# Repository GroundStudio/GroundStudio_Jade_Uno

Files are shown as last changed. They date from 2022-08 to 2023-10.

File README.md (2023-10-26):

GroundStudio Jade Uno
====================================
(https://ardushop.ro/ro/home/1728-placa-de-dezvoltare-jade-uno.html)

Get it from [ardushop.ro](https://ardushop.ro/ro/home/1728-placa-de-dezvoltare-jade-uno.html)

Explore all the GroundStudio products at [GroundStudio.ro](https://groundstudio.ro/)

Description
-------------------
ATMEGA328P based development board, 32kBytes of In-System Self-Programmable Flash program memory,  1kBytes EEPROM, 2kBytes Internal SRAM, 6 PWM Channels, 20 Digital Pins including 4 channel 10 bit ADC Pins and HT42B534-2 for USB comunication.

Contents
-------------------

* [/Documentation](https://github.com/GroundStudio/GroundStudio_Jade_Uno/tree/main/Documentation) -- Pinout.
* [/Hardware](https://github.com/GroundStudio/GroundStudio_Jade_Uno/tree/main/Hardware) -- Schematics, layout.

Versions
-------------------
*(Not all tags shown)*

* [REV0.2]

License
-------------------

This is released under the [Attribution-ShareAlike 4.0 International (CC BY-SA 4.0)](https://creativecommons.org/licenses/by-sa/4.0/) license.
**You are welcome to use this for commercial purposes.**

Please consider contributing back to this project or others to help the open-source hardware community continue to thrive and grow!

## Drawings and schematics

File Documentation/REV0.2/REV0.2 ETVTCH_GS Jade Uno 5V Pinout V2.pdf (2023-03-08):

# GroundStudio Jade Uno

## ISP Port

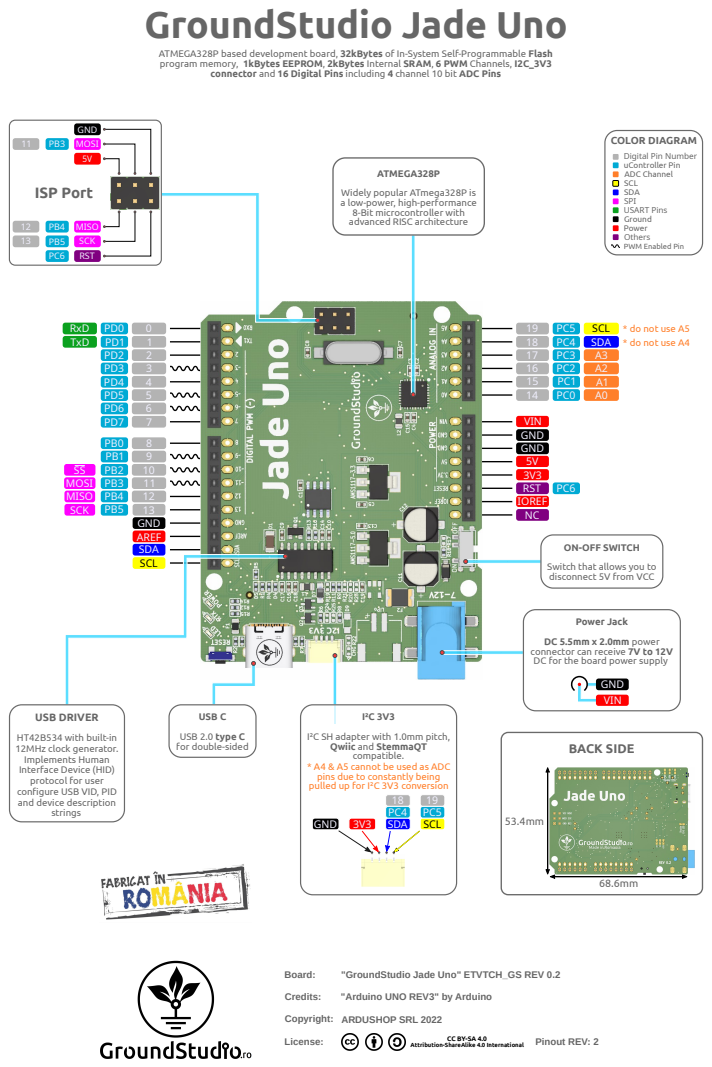
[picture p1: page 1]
Board:; Credits:; "Arduino UNO REV3" by Arduino; Copyright:; License:; ARDUSHOP SRL 2022; Pinout REV: 2; ATMEGA328P; GND MOSI 5V; PB5 SCK; MISO; RST; MOSI PB3; MISO PB4; TxD PD1; RxD PD0; SCK PB5; SCL; SDA; AREF; GND; VIN; RST PC6; IOREF; USB DRIVER; strings; BACK SIDE; I²C 3V3; SDA SCL; GND 3V3; * do not use A5 * do not use A4

ATMEGA328P based development board, 32kBytes of In-System Self-Programmable Flash
program memory, 1kBytes EEPROM, 2kBytes Internal SRAM, 6 PWM Channels, I2C_3V3

connector and 16 Digital Pins including 4 channel 10 bit ADC Pins

COLOR DIAGRAM
Digital Pin Number
uController Pin
ADC Channel
SCL
SDA
SPI
USART Pins
Ground
Power
Others
PWM Enabled Pin

Widely popular ATmega328P is
a low-power, high-performance
8-Bit microcontroller with
advanced RISC architecture

ON-OFF SWITCH
Switch that allows you to
disconnect 5V from VCC

Power Jack
DC 5.5mm x 2.0mm power
connector can receive 7V to 12V
DC for the board power supply

USB C
USB 2.0 type C
for double-sided

HT42B534 with built-in
12MHz clock generator.
Implements Human
Interface Device (HID)
protocol for user
configure USB VID, PID
and device description

I²C SH adapter with 1.0mm pitch,
Qwiic and StemmaQT
compatible.

* A4 & A5 cannot be used as ADC
pins due to constantly being
pulled up for I²C 3V3 conversion

"GroundStudio Jade Uno" ETVTCH_GS REV 0.2

Attribution-ShareAlike 4.0 International

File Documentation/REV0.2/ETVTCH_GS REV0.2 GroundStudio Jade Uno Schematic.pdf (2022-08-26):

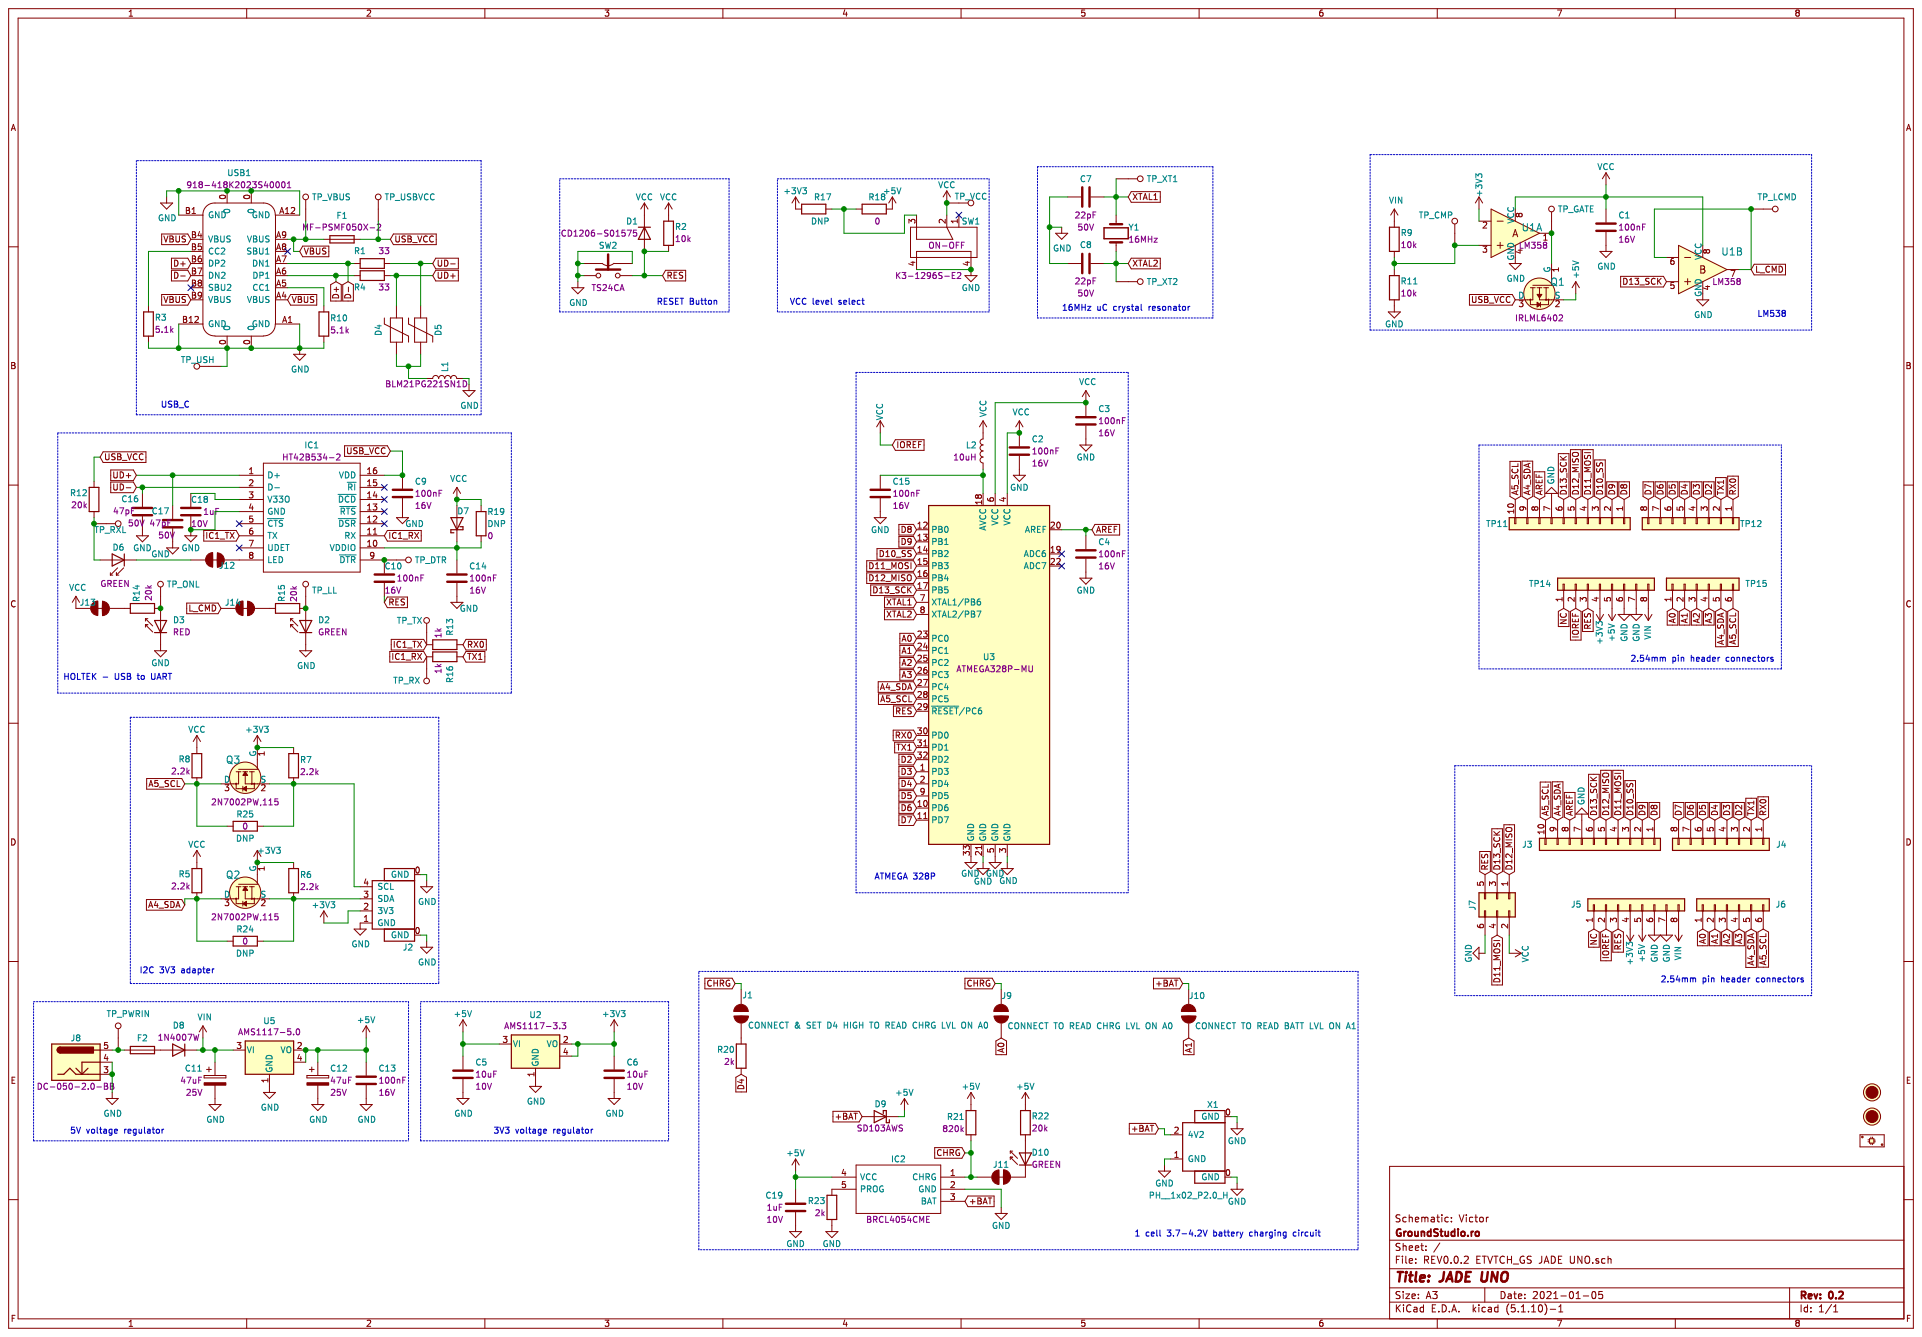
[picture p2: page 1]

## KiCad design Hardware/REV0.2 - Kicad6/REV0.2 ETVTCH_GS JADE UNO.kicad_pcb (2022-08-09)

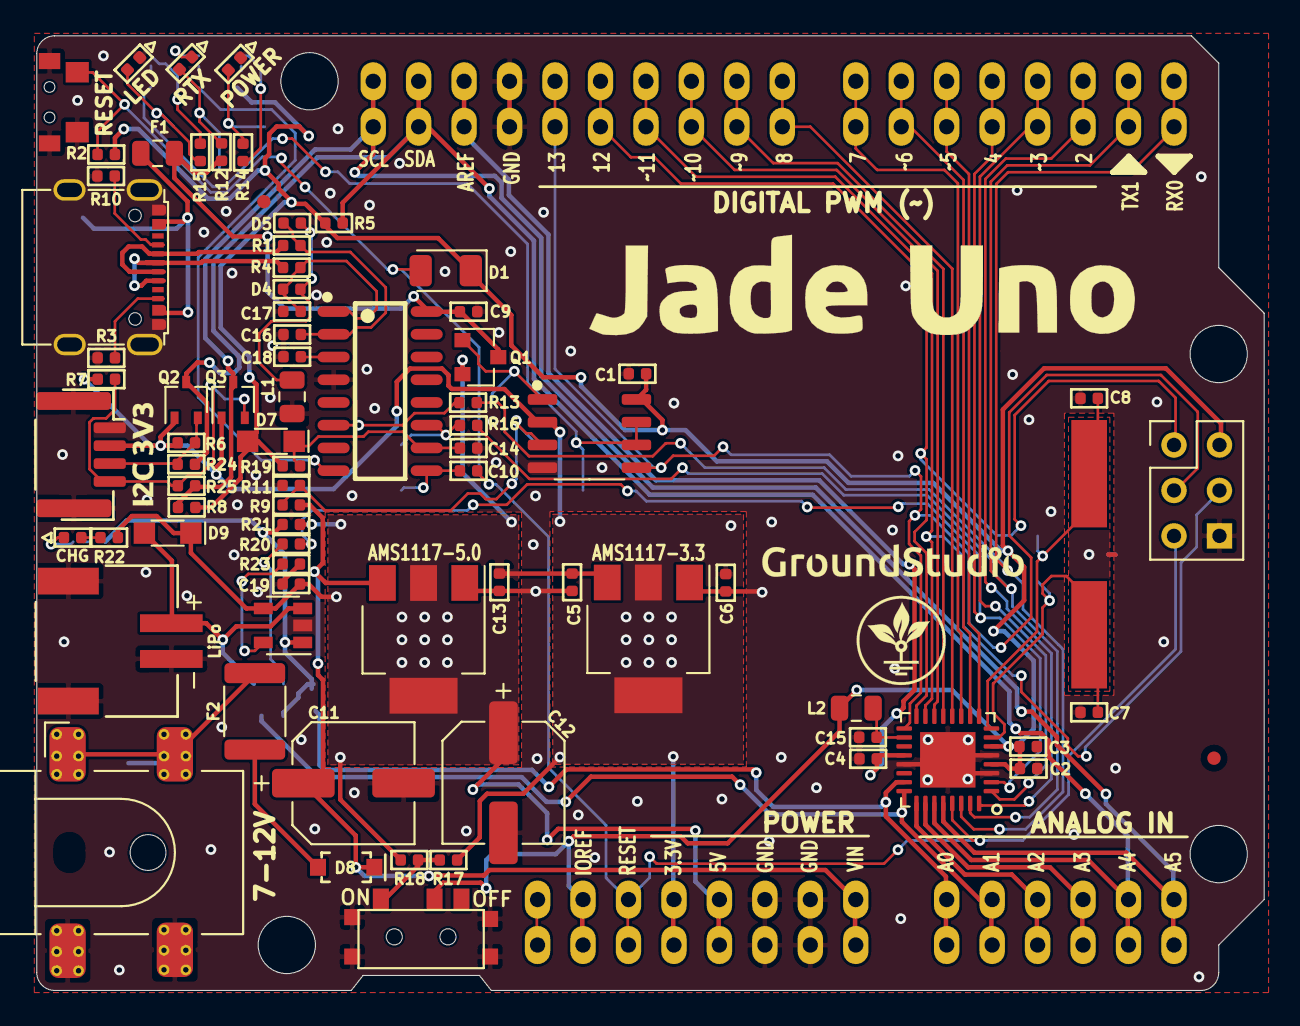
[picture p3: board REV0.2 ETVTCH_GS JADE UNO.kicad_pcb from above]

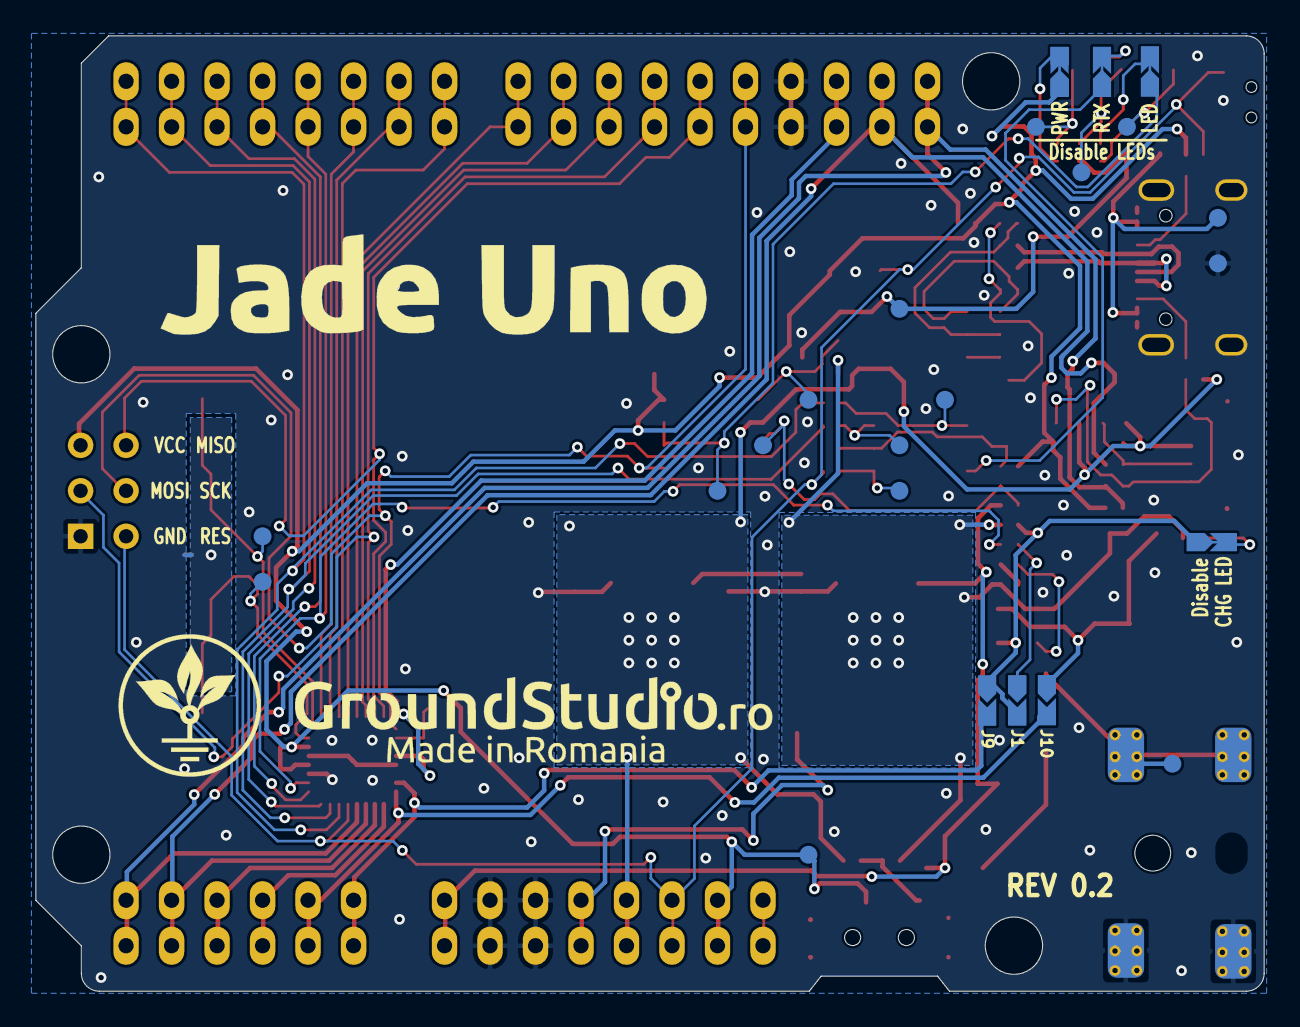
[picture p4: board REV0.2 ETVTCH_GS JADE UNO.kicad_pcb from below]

Board: 2 copper layers, 68.6 x 53.3 mm, 108 parts (11 on the bottom side), 66 nets.

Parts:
C1, C2, C3, C4, C9, C10, C13, C14, C15: C_0402_100nF_16V; C_0402
C5, C6: C_0402_10uF_10V; C_0402
C7, C8: C_0402_22pF_50V; C_0402
C11, C12: CP_Elec_6.3x5.4_47uF_25V; CP_Elec_6.3x5.4
C16, C17: C_0402_47pF_50V; C_0402
C18, C19: C_0402_1uF_10V; C_0402
D1: D_1206_CD1206-S01575; D_1206
D2, D6, D10: LED_0402_GREEN; LED_0402
D3: LED_0402_RED; LED_0402
D4, D5: R_0402_PS0402V014AT; R_0402
D7, D9: SOD-323 SD103AWS; SOD-323
D8: SOD-123 1N4007W; SOD-123
F1: Fuse_0805_MF-PSMF050X-2; R_0805
F2: Fuse_1812_MF-MSMF050-2; Fuse_1812
FID1, FID2: Fiducial; Fiducial_0.75mm_Mask1.5mm
IC1: SOP-16_150MIL HT42B534-2; SOP-16_150MIL
IC2: SOT23-5 BRCL4054CME; SOT-23-5
J1: CONNECT & SET D4 HIGH TO READ CHRG LVL ON A0; SolderJumper_NO
J2: SH_1x04_P1.0_H; SH__1x04_P1.00mm_Horizontal
J3: PinHeader_1x10_P2.54_V_F; PinHeader_1x10_P2.54mm_Vertical_Female
J4, J5: PinHeader_1x8_P2.54_V_F; PinHeader_1x08_P2.54mm_Vertical_Female
J6: PinHeader_1x6_P2.54_V_F; PinHeader_1x06_P2.54mm_Vertical_Female
J7: PinHeader_2x03_P2.54_V_M; PinHeader_2x03_P2.54mm_Vertical_Male
J8: DC-005-5.5-Barr_Jck_SMD; DC-005-5.5-2.0MM-SMD
J9: CONNECT TO READ CHRG LVL ON A0; SolderJumper_NO
J10: CONNECT TO READ BATT LVL ON A1; SolderJumper_NO
J11, J12, J13, J14: SolderJumper_NC
L1: L_0805_BLM21PG221SN1D; L_0805
L2: L_0805_SCMI201209X100KT; L_0805
Q1: SOT-23 IRLML6402; SOT-23
Q2, Q3: SOT-323 2N7002PW; SOT-323_SC-70
R1, R4: R_0402_33; R_0402
R2, R9, R11: R_0402_10k; R_0402
R3, R10: R_0402_5.1k; R_0402
R5, R6, R7, R8: R_0402_2.2k; R_0402
R12, R14, R15, R22: R_0402_20k; R_0402
R13, R16: R_0402_1k; R_0402
R17, R19, R24, R25: DNP; R_0402
R18: R_0402_0; R_0402
R20, R23: R_0402_2k; R_0402
R21: R_0402_820k; R_0402
SW1: K3-1296S-E2
SW2: TS24CA
TP1: TP_VBUS; TestPoint
TP2: TP_USBVCC; TestPoint
TP3: TP_LCMD; TestPoint
TP4: TP_USH; TestPoint
TP5: TP_GATE; TestPoint
TP6: TP_CMP; TestPoint
TP7: TP_TX; TestPoint
TP8: TP_LL; TestPoint
TP9: TP_RX; TestPoint
TP10: TP_ONL; TestPoint
TP11: DNP; PinHeader_1x10_P2.54mm_Vertical_Female
TP12, TP14: DNP; PinHeader_1x08_P2.54mm_Vertical_Female
TP13: TP_RXL; TestPoint
TP15: DNP; PinHeader_1x06_P2.54mm_Vertical_Female
TP16: TP_XT1; TestPoint
TP17: TP_VCC; TestPoint
TP18: TP_XT2; TestPoint
TP19: TP_DTR; TestPoint
TP23: TP_PWRIN; TestPoint
U1: SOP-8_3.9x4.9_P1.27 LM358; SOP-8_3.9x4.9mm_P1.27mm
U2: SOT-223 AMS1117-3.3; SOT-223
U3: ATmega328P-MU; QFN-32-1EP_5x5mm_P0.5mm_EP3.1x3.1mm
U5: SOT-223 AMS1117-5.0; SOT-223
USB1: USB_C 918-418K2023S40001; USB_C_C167321
X1: PH__1x02_P2.0_H; PH__1x02_P2.00mm_Horizontal
Y1: HC49-SMD 5M0-1600A2020; Crystal_HC49-SMD

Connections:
+3V3: C6.1, J2.2, J5.4, Q2.1, Q3.1, R6.1, R7.1, R17.2, TP14.4, U1.2, U2.2, U2.4
+5V: C5.1, C12.1, C13.1, C19.1, D9.1, IC2.4, J5.5, Q1.2, R18.1, R21.1, R22.2, TP14.5, U2.3, U5.2, U5.4
+BAT: D9.2, IC2.3, J10.1, X1.2
A0: J6.1, J9.2, TP15.1, U3.23
A1: J6.2, J10.2, TP15.2, U3.24
A2: J6.3, TP15.3, U3.25
A3: J6.4, TP15.4, U3.26
A4_SDA: J3.9, J6.5, Q2.3, R5.1, R24.2, TP11.9, TP15.5, U3.27
A5_SCL: J3.10, J6.6, Q3.3, R8.1, R25.2, TP11.10, TP15.6, U3.28
AREF: C4.1, J3.8, TP11.8, U3.20
CHRG: IC2.1, J1.2, J9.1, J11.1, R21.2
D2: J4.3, TP12.3, U3.32
D3: J4.4, TP12.4, U3.1
D4: J4.5, R20.1, TP12.5, U3.2
D5: J4.6, TP12.6, U3.9
D6: J4.7, TP12.7, U3.10
D7: J4.8, TP12.8, U3.11
D8: J3.1, TP11.1, U3.12
D9: J3.2, TP11.2, U3.13
D10_SS: J3.3, TP11.3, U3.14
D11_MOSI: J3.4, J7.4, TP11.4, U3.15
D12_MISO: J3.5, J7.1, TP11.5, U3.16
D13_SCK: J3.6, J7.3, TP11.6, U1.5, U3.17
D+: R4.1, USB1.A6, USB1.B6
D-: R1.1, USB1.A7, USB1.B7
GND: C1.2, C2.2, C3.2, C4.2, C5.2, C6.2, C7.1, C8.1, C9.2, C11.2, C12.2, C13.2, C14.2, C15.2, C16.1, C17.1, C18.2, C19.2, D2.1, D3.1, IC1.4, IC2.2, J2.0, J2.1, J3.7, J5.6, J5.7, J7.6, J8.3, J8.4, L1.2, R3.1, R10.2, R11.1, R23.1, SW1.4, SW2.1, SW2.2, SW2.3, TP4.~, TP11.7, TP14.6, TP14.7, U1.4, U2.1, U3.3, U3.5, U3.21, U3.33, U5.1, USB1.0, USB1.A1, USB1.A12, USB1.B1, USB1.B12, X1.0, X1.1
IC1_RX: IC1.11, R16.2, TP9.~
IC1_TX: IC1.6, R13.2, TP7.~
IOREF: C1.1, C2.1, C3.1, D1.1, D7.2, J5.2, J7.2, J13.1, L2.1, R2.2, R5.2, R8.2, R19.1, SW1.2, TP14.2, TP17.~, U1.8, U3.4, U3.6
L_CMD: J14.1, TP3.~, U1.6, U1.7
NC: J5.1, TP14.1
unnamed: C10.1, IC1.9, TP19.~
unnamed: C14.1, D7.1, IC1.10, R19.2
unnamed: C15.1, L2.2, U3.18
unnamed: C18.1, IC1.3
unnamed: D2.2, R15.2, TP8.~
unnamed: D3.2, R14.2, TP10.~
unnamed: D4.1, D5.2, L1.1
unnamed: D6.1, J12.2
unnamed: D6.2, R12.1, TP13.~
unnamed: D8.2, F2.1
unnamed: D10.1, J11.2
unnamed: D10.2, R22.1
unnamed: F2.2, J8.5, TP23.~
unnamed: IC1.8, J12.1
unnamed: IC2.5, R23.2
unnamed: J1.1, R20.2
unnamed: J2.3, Q2.2, R6.2, R24.1
unnamed: J2.4, Q3.2, R7.2, R25.1
unnamed: J13.2, R14.1
unnamed: J14.2, R15.1
unnamed: Q1.1, TP5.~, U1.1
unnamed: R3.2, USB1.B5
unnamed: R10.1, USB1.A5
unnamed: R9.1, R11.2, TP6.~, U1.3
unnamed: R17.1, R18.2, SW1.3
RES: C10.2, D1.2, J5.3, J7.5, R2.1, SW2.4, TP14.3, U3.29
RX0: J4.1, R13.1, TP12.1, U3.30
TX1: J4.2, R16.1, TP12.2, U3.31
UD+: C17.2, D4.2, IC1.1, R4.2
UD-: C16.2, D5.1, IC1.2, R1.2
USB_VCC: C9.1, F1.1, IC1.16, Q1.3, R12.2, TP2.~
VBUS: F1.2, TP1.~, USB1.A4, USB1.A9, USB1.B4, USB1.B9
VIN: C11.1, D8.1, J5.8, R9.2, TP14.8, U5.3
XTAL1: C7.2, TP16.~, U3.7, Y1.1
XTAL2: C8.2, TP18.~, U3.8, Y1.2

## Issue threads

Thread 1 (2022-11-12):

How to make A4 and A5 pins useful again?

slavicd, 2022-11-12:
It looks like A4 and A5 pins are pull-up by default in order to [make the board R3-compatible](https://ardushop.ro/ro/home/1728-placa-de-dezvoltare-jade-uno.html). Is there a way to revert this behaviour so that A4 and A5 are useful as analog inputs?

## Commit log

2022-08-09 - initial commit
    [REV0.2 ETVTCH_GS JADE UNO.kicad_pcb, REV0.2 ETVTCH_GS JADE UNO.kicad_sch]
2022-08-26 - added schematic pdf file
2022-08-26 - added "Kicad6" to revision folder name
    [REV0.2 ETVTCH_GS JADE UNO.kicad_pcb, REV0.2 ETVTCH_GS JADE UNO.kicad_sch]
2023-03-08 - fixed the wrong size values. - added I2C 3V3 connector in description. - changed number of digital pins to 16 in description. - highlighted A4 & A5 pins to not be used.
2023-10-26 - added .step 3D file of the board
